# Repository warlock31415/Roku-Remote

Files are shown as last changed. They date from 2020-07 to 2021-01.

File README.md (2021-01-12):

# Roku Remote

## Introduction
My roomate keeps loosing the remote to the TV. So I made a spare remote to work with our TV and simulates the same behaviour as the original remote. The remote can also work via micro USB as well as a Lithium polymer battery. This project was my first forray into ARM microcontrollers and ST's Hardware Abstraction Layer (HAL).  

## Recording button codes
The Roku remote work on a IR signal and the data is modulated on the 37 kHz signal. The NEC protocol decription can be found [here](https://techdocs.altium.com/display/FPGA/NEC+Infrared+Transmission+Protocol) . A Analog Discovery along with the TSOP382 (IR receiver) was used to record the signal. The receiver demodulates the signal internally and only ouputs the data bits. Each button was pressed and the corresponding code was recorded. It was noted that each button had 2 codes associated with it. The first one was transmitted when the button was pressed and the second was transmitted when the button was held down. Only the last 4 bytes of the codes are shown here as the first 4 bytes are always the same (0x57E3).

The recorded button codes are as follows:
| Button | Code in HEX |  Last 4 bytes of the held down code|
|---|---| ---|
| Power  | 0x57E3E817 | 0x57E3E916 | 
| Back | 0x57E36699 | 0x57E36798 |
| Home | 0xCO3F | 0xC13E |
| ↑ | 0x9867 | 0x9966 |
| → | 0xB44B | 0xB54A |
| ↓ | 0xCC33 | 0xCD32 |
| ← | 0x7887 | 0x7986 |
| OK | 0x54AB | 0x55AA |
| V+ | 0xF00F | 0xF10E |
| V- | 0x08F7 | 0x09F6 |
| Mute | 0x04FB | 0x05FA |

## The code
ST's Nucleo-F401RE(497-14360-ND) was used to build the remote on a breadboard. Although, a STM32L052K8T was actually used in the final prototype due to its lower power consumption as compared to the STM32F401RE.

The HAL does not have a microsecond delay so a timer was used. The following code shows how this works:
```
void delay_us(uint16_t time)
{
	TIM6->ARR = time; 	 	// Load time into Auto Reload Register
	TIM6->CR1 |= (1<<0); 	// start timer

	while(TIM6->CR1 & 1);	// Wait for timer to elapse
}
```
ST's Cube IDE makes it very easy to set up and use timers graphically. To generate the carrier another 16-bit advanced timer was used in PWM mode. The STM32F401RE has 16-bit prescale register which allows just about any frequency. This, combined with the Auto-Preload Register, one can generate just about any frequency signal with any duty cycle. So a 37kHz carrier with a 30% duty cycle, for efficiency, was generated. This Prescale and AR registers are especially more advatageous to an ATMEGA328P which only has a couple of prescalers to choose from and the "auto reload register" is the only way to control frequency. And hence duty cycle cannot be controlled in the same way.

Each button code consists of 3 sections. The start code, specific button code and the end code. This can be seen in Table 1.
## PCB
The PCB was made in Eagle and manufactured by JLCPCB. All components were hand soldered. Including, the STM32L052K8T. The blue silk screen on the PCBs look pretty good. 
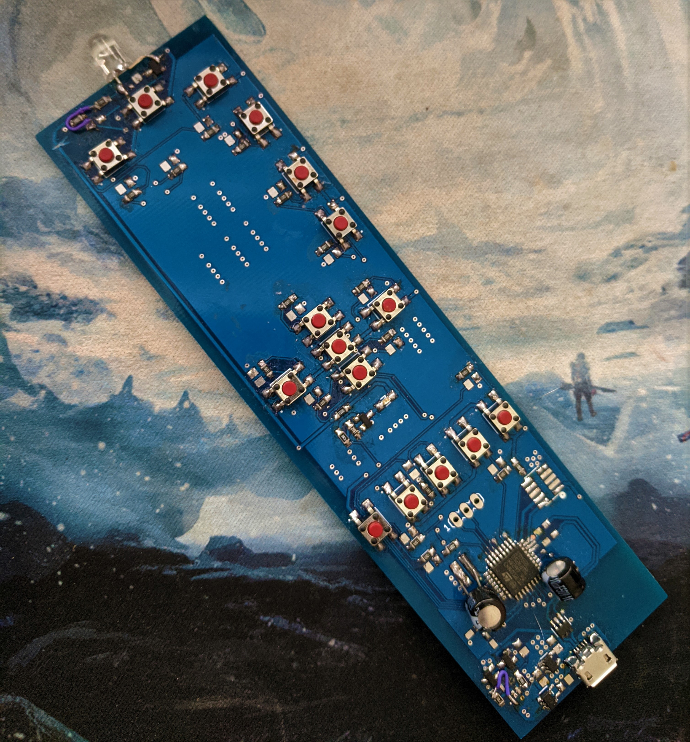
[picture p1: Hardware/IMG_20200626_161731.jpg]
PCB Image


## Shortcomings
- The SMD IR transmitter that was spec'd for the project didn't seem to work properly. So a THT transmitter, was was used to test the breadboard prototype, was soldered in its place. Some wire bodging was needed to accomplish this.
- The battery protection circuitry was not correctly wired up (Some kind of issue with Battery GND vs system GND).

## TO DO
- Redo board to eliminate wire bodges.
- Make a case for the board.

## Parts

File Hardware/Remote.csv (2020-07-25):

Qty | Value | Device | Package | Parts | Description | AVAILABILITY | BUILT_BY | COPYRIGHT | DESCRIPTION | DIGI-KEY_PART_NUMBER | DIGI-KEY_PURCHASE_URL | MANUFACTURER | MANUFACTURER_PART_NUMBER | MF | MP | MPN | OC_FARNELL | OC_NEWARK | PACKAGE | POPULARITY | PRICE | SOURCELIBRARY | SPICEPREFIX | VENDOR
1 |  | 20021121-00010C4LF | CONN_00010C4LF_AMP | J2 |  |  | EMA_Matt | Copyright (C) 2018 Accelerated Designs. All rights reserved |  |  |  |  | 20021121-00010C4LF |  |  |  |  |  |  |  |  | Amphenol_2019-10-30 |  | Amphenol
1 |  | MA03-1 | MA03-1 | SV1 | PIN HEADER |  |  |  |  |  |  |  |  |  |  |  | unknown | unknown
1 |  | MCP73811T-420I/OT | SOT95P280X145-5N | IC4 |  |  |  |  | Charger IC Lithium Ion/Polymer SOT-23-5 | MCP73811T-420I/OTCT-ND | https://www.digikey.com/product-detail/en/microchip-technology/MCP73811T-420I-OT/MCP73811T-420I-OTCT-ND/1649474 |  |  | Microchip | MCP73811T-420I/OT |  |  |  | SOT-23 Microchip
1 |  | S2B-PH-SM4-TB(LF)(SN) | JST_S2B-PH-SM4-TB(LF)(SN) | J1 | PH Series 2 Position 2 mm Pitch Surface Mount Side Entry Shrouded Header | Unavailable |  |  | Connector Header Surface Mount, Right Angle 2 position 0.079 _2.00mm_ |  |  |  |  | JST Sales | S2B-PH-SM4-TB_LF__SN_ |  |  |  | None |  | None
1 |  | TPS73632DBVTDBV5-M | DBV5-M | IC5 |  |  | EMA_UL_Team |  |  |  |  | Texas Instruments | TPS73632DBVT |  |  |  |  |  |  |  |  |  |  | Texas Instruments
1 | 100 | R-US_R0805W | R0805W | R22 | RESISTOR, American symbol |  |  |  |  |  |  |  |  |  |  |  |  |  |  | 0 |  |  | R
1 | 100k | R-US_R0805W | R0805W | R29 | RESISTOR, American symbol |  |  |  |  |  |  |  |  |  |  |  |  |  |  | 0 |  |  | R
20 | 100nF | C-USC0805K | C0805K | C1, C2, C4, C5, C6, C7, C8, C9, C10, C11, C12, C13, C14, C15, C16, C17, C18, C19, C20, C25 | CAPACITOR, American symbol |  |  |  |  |  |  |  |  |  |  |  |  |  |  | 19 |  |  | C
1 | 10118193-0001LF | 10118193-0001LF | FCI_10118193-0001LF | J3 | Micro USB B Type Receptacle |  |  |  | USB - micro B USB 2.0 Receptacle Connector 5 Position Surface Mount, Right Angle | Through Hole | 609-4616-1-ND | https://www.digikey.com/product-detail/en/amphenol-icc-fci/10118193-0001LF/609-4616-1-ND/2785380 |  |  | Amphenol ICC | 10118193-0001LF |  |  |  | None
4 | 10k | R-US_R0805W | R0805W | R1, R2, R23, R25 | RESISTOR, American symbol |  |  |  |  |  |  |  |  |  |  |  |  |  |  | 0 |  |  | R
2 | 10uF | C-USC0805K | C0805K | C3, C21 | CAPACITOR, American symbol |  |  |  |  |  |  |  |  |  |  |  |  |  |  | 19 |  |  | C
16 | 1k | R-US_R0805W | R0805W | R3, R4, R5, R6, R7, R8, R9, R10, R11, R12, R13, R14, R15, R16, R17, R18 | RESISTOR, American symbol |  |  |  |  |  |  |  |  |  |  |  |  |  |  | 0 |  |  | R
3 | 1uF | C-USC0805K | C0805K | C22, C23, C24 | CAPACITOR, American symbol |  |  |  |  |  |  |  |  |  |  |  |  |  |  | 19 |  |  | C
1 | 2.7k | R-US_R0805W | R0805W | R27 | RESISTOR, American symbol |  |  |  |  |  |  |  |  |  |  |  |  |  |  | 0 |  |  | R
3 | 22 | R-US_R0805W | R0805W | R19, R20, R30 | RESISTOR, American symbol |  |  |  |  |  |  |  |  |  |  |  |  |  |  | 0 |  |  | R
1 | 330 | R-US_R0805W | R0805W | R28 | RESISTOR, American symbol |  |  |  |  |  |  |  |  |  |  |  |  |  |  | 0 |  |  | R
2 | 470 | R-US_R0805W | R0805W | R24, R26 | RESISTOR, American symbol |  |  |  |  |  |  |  |  |  |  |  |  |  |  | 0 |  |  | R
1 | 50k | R-US_R0805W | R0805W | R21 | RESISTOR, American symbol |  |  |  |  |  |  |  |  |  |  |  |  |  |  | 0 |  |  | R
1 | AP9101CK6-CQTRG1 | AP9101CK6-CQTRG1 | SOT95P280X140-6N | IC6 | None | Unavailable |  |  | Battery Battery Protection IC Lithium Ion/Polymer SOT-26 |  |  |  |  | Diodes Inc. | AP9101CK6-CQTRG1 |  |  |  | SOT-23 Diodes Inc. |  | None
1 | APA3010SF4C | APA3010SF4C | APA3010SF4C | D1 | DIO-10854 |  |  |  | Infrared _IR_ Emitter 880nm 1.3V 50mA 0.4mW/sr @ 20mA 120° 2-SMD, No Lead | 754-1070-1-ND | https://www.digikey.com/product-detail/en/kingbright/APA3010SF4C/754-1070-1-ND/1747787 |  |  | Kingbright | APA3010SF4C |  |  |  | SMD-2 Kingbright
4 | BSS138 | BSS138 | BSS138 | IC2, IC3, IC7, IC8 | BSS138 | Unavailable |  |  | N-Channel 50V 220mA _Ta_ 360mW _Ta_ Surface Mount SOT-23-3 |  |  |  |  | MICROSS/On Semiconductor | BSS138 |  |  |  | TO-236-3 Micross |  | None
1 | STM32L052K8T | STM32L052K8T | QFP80P900X900X160-32N | IC1
16 | TL3305AF260QG | TL3305AF260QG | SW_TL3305AF260QG | SW1, SW2, SW3, SW4, SW5, SW6, SW7, SW8, SW9, SW10, SW11, SW12, SW13, SW14, SW15, SW16 | Switch Tactile Spst-No 50ma 12v |  |  |  | Tactile Switch SPST-NO Top Actuated Surface Mount | EG5353CT-ND | https://www.digikey.com/product-detail/en/e-switch/TL3305AF260QG/EG5353CT-ND/5816198 |  |  | E-Switch | TL3305AF260QG |  |  |  | LQFP-48 E-Switch
1 | USBLC6-2SC6SOT23-6L-M | USBLC6-2SC6SOT23-6L-M | SOT23-6L-M | IC9 |  |  | EMA_UL_Team |  |  |  |  |  | USBLC6-2SC6 |  |  |  |  |  |  |  |  |  |  | STMicroelectronics
1 | WL-SMCW-150120GS75000-G | WL-SMCW-150120GS75000-G | WL-SMCW_1206 | D2 | SMD mono-color Chip LED | Unavailable |  |  | Green 570nm LED Indication - Discrete 2V 0603 _1608 Metric_ |  |  |  |  | Wurth Electronics | 150060VS75000 |  |  |  | 0603 Wurth Electronics |  | None

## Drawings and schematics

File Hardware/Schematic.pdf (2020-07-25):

A

A

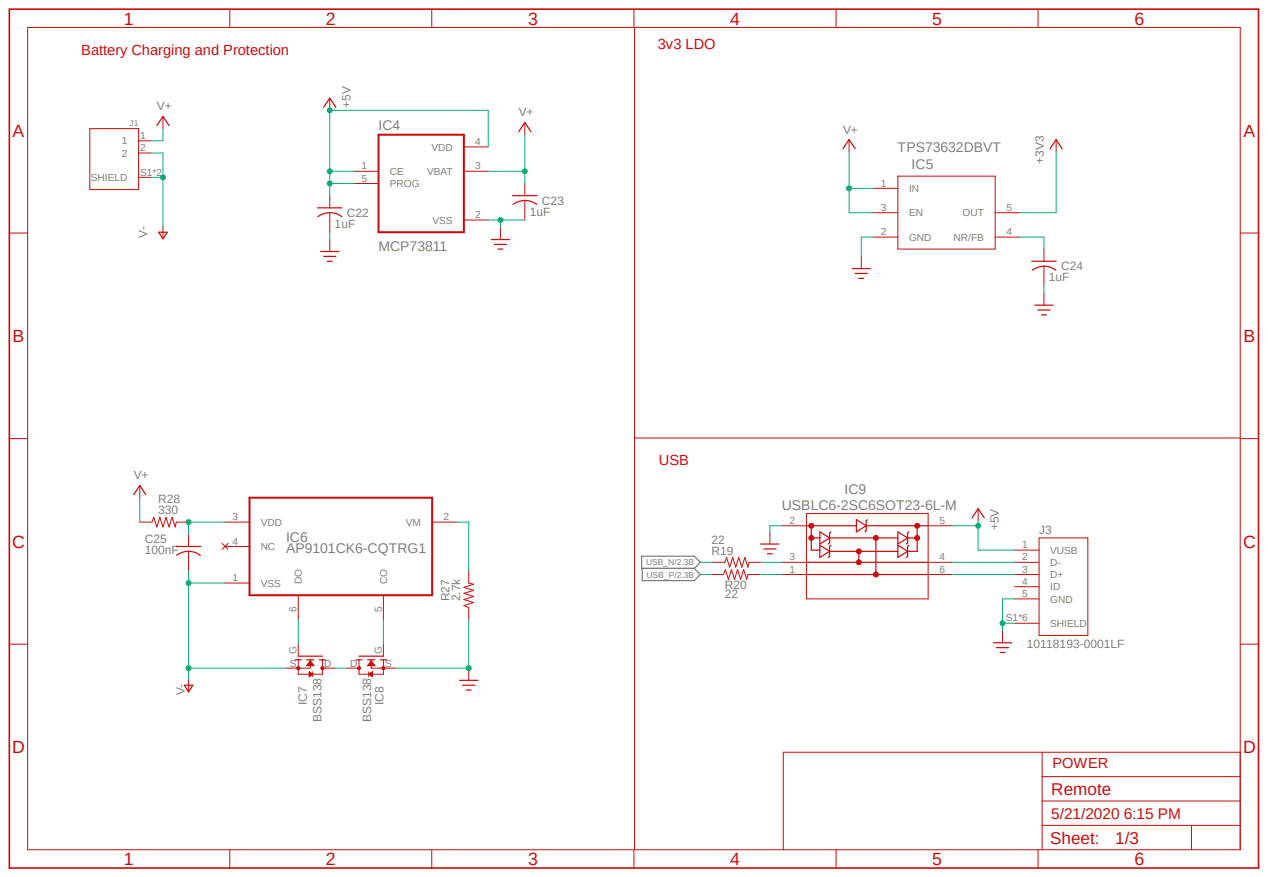
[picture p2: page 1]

C | IC9 USBLC6-2SC6SOT23-6L-M | C

# 10k ⁺³V³

A

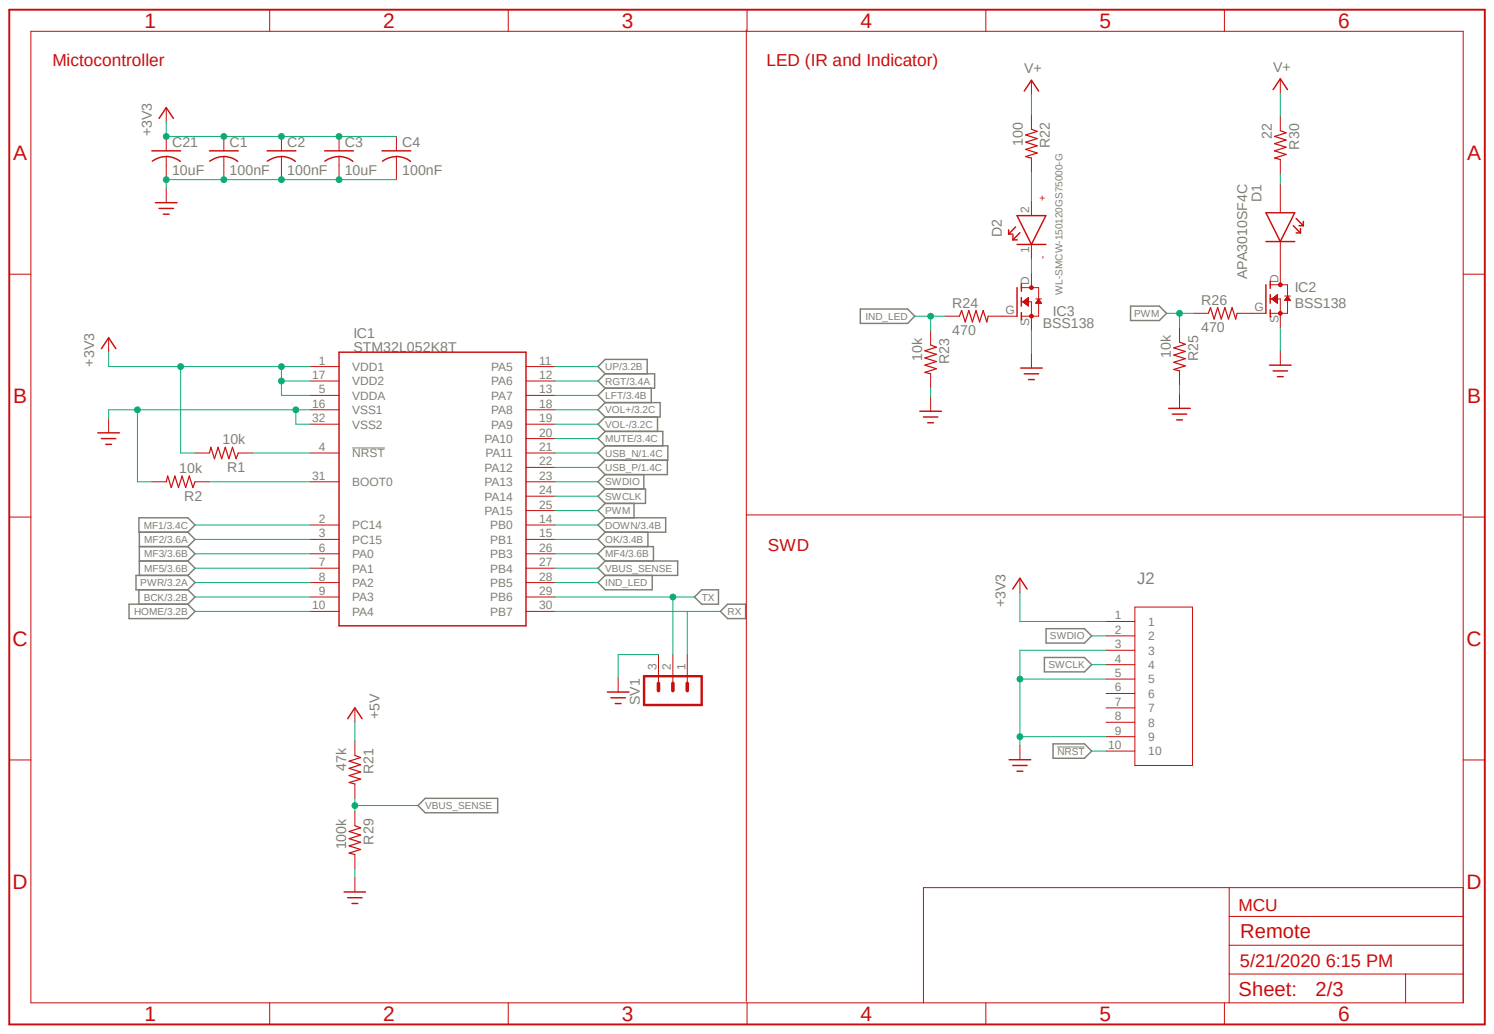
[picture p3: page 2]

# 100nF +3V³

A

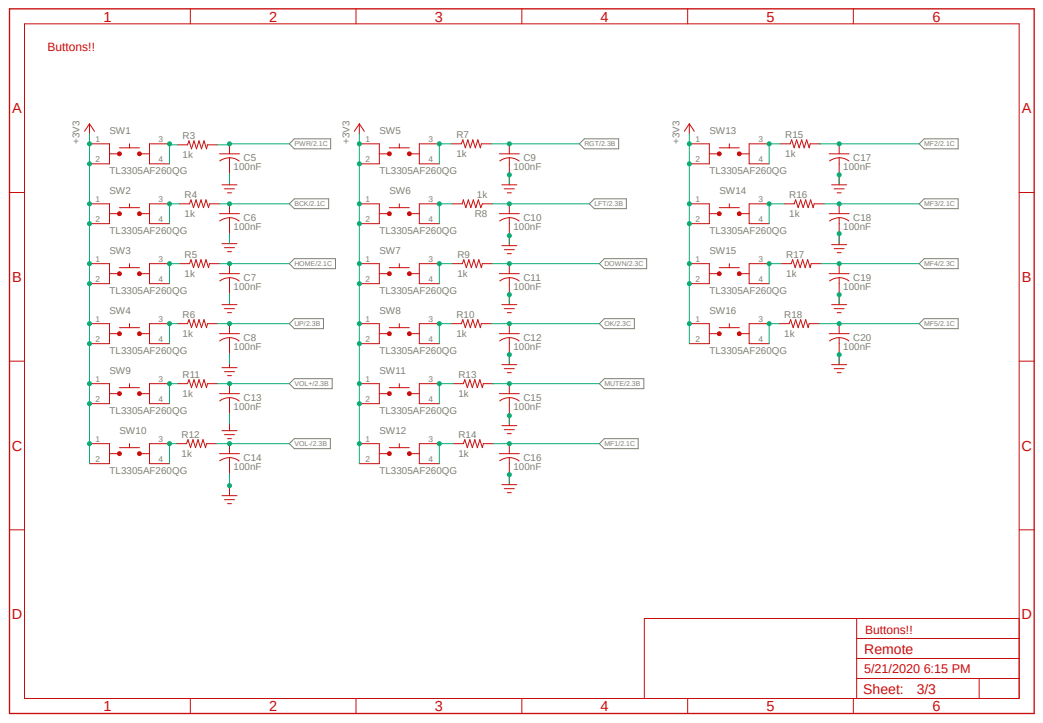
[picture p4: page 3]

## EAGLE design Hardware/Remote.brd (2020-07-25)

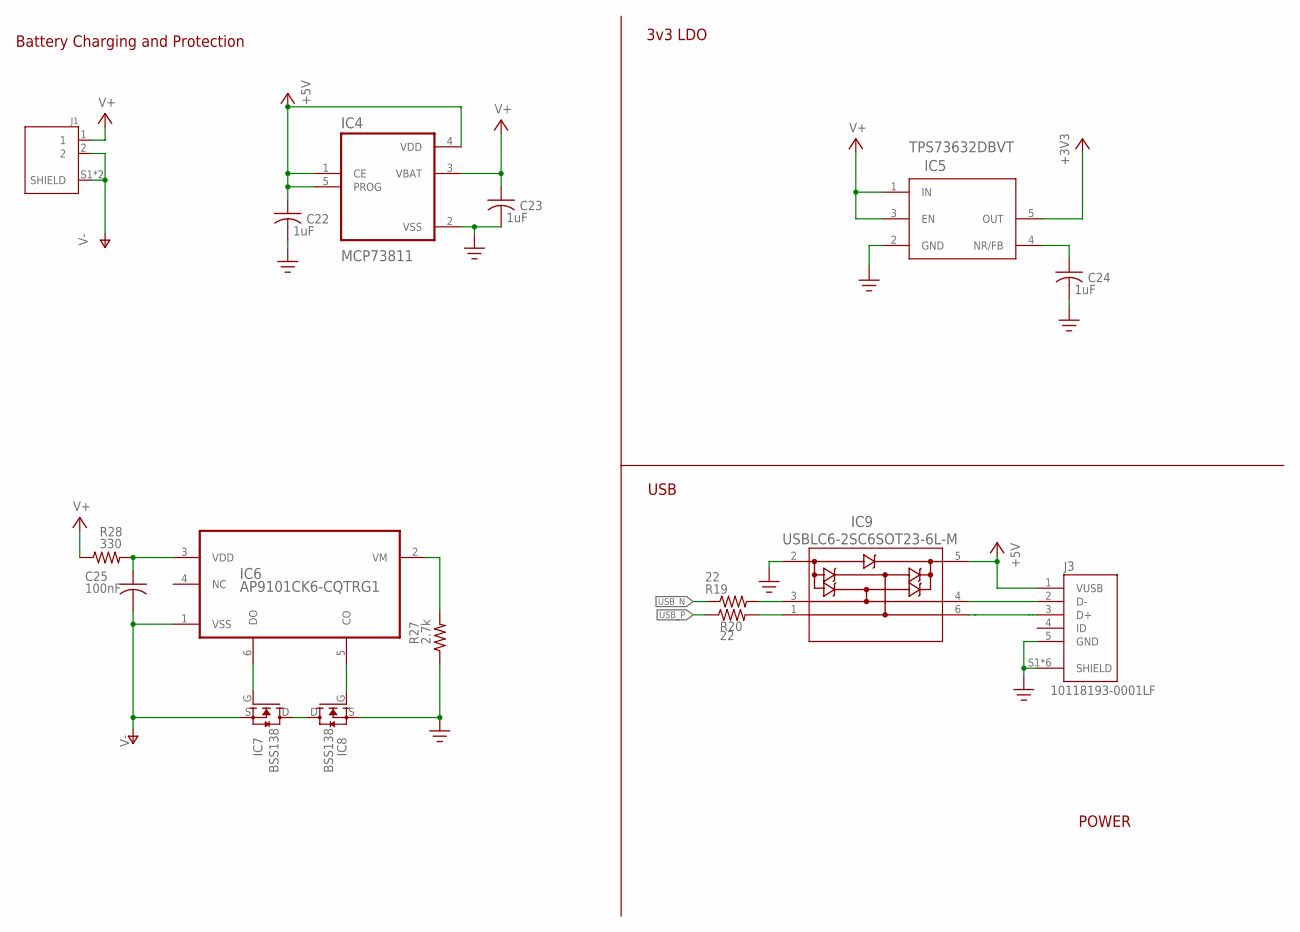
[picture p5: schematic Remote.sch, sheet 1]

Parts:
C22, C23, C24: 1uF; C0805K
C25: 100nF; C0805K
IC4: MCP73811; SOT95P280X145-5N
IC5: TPS73632DBVT; DBV5-M
IC6: AP9101CK6-CQTRG1; SOT95P280X140-6N
IC7, IC8: BSS138
IC9: USBLC6-2SC6SOT23-6L-M; SOT23-6L-M
J1: S2B-PH-SM4-TB(LF)(SN); JST_S2B-PH-SM4-TB(LF)(SN)
J3: 10118193-0001LF; FCI_10118193-0001LF
R19, R20: 22; R0805W
R27: 2.7k; R0805W
R28: 330; R0805W

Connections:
+3V3: IC5.5 (OUT); also elsewhere on the board
+5V: C22.1, IC4.1 (CE), IC4.4 (VDD), IC4.5 (PROG), IC9.5 (VBUS), J3.1 (VUSB); also elsewhere on the board
GND: C22.2, C23.2, C24.2, IC4.2 (VSS), IC5.2 (GND), IC8.S, IC9.2 (GND), J3.5 (GND), J3.S1 (SHIELD), J3.S2 (SHIELD), J3.S3 (SHIELD), J3.S4 (SHIELD), J3.S5 (SHIELD), J3.S6 (SHIELD), R27.1; also elsewhere on the board
unnamed: IC6.6 (DO), IC7.G
unnamed: IC6.5 (CO), IC8.G
unnamed: IC7.D, IC8.D
unnamed: C24.1, IC5.4 (NR/FB)
unnamed: IC6.2 (VM), R27.2
unnamed: C25.1, IC6.3 (VDD), R28.2
USB2_N: IC9.4 (I/O2), J3.2 (D-)
USB2_P: IC9.6 (I/O1), J3.3 (D+)
USB3_N: IC9.3 (I/O2_2), R19.2
USB3_P: IC9.1 (I/O1_2), R20.2
USB_N: R19.1; also elsewhere on the board
USB_P: R20.1; also elsewhere on the board
V+: C23.1, IC4.3 (VBAT), IC5.1 (IN), IC5.3 (EN), J1.1, R28.1; also elsewhere on the board
V-: C25.2, IC6.1 (VSS), IC7.S, J1.2, J1.S1 (SHIELD), J1.S2 (SHIELD)

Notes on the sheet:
Battery Charging and Protection
3v3 LDO
USB
POWER

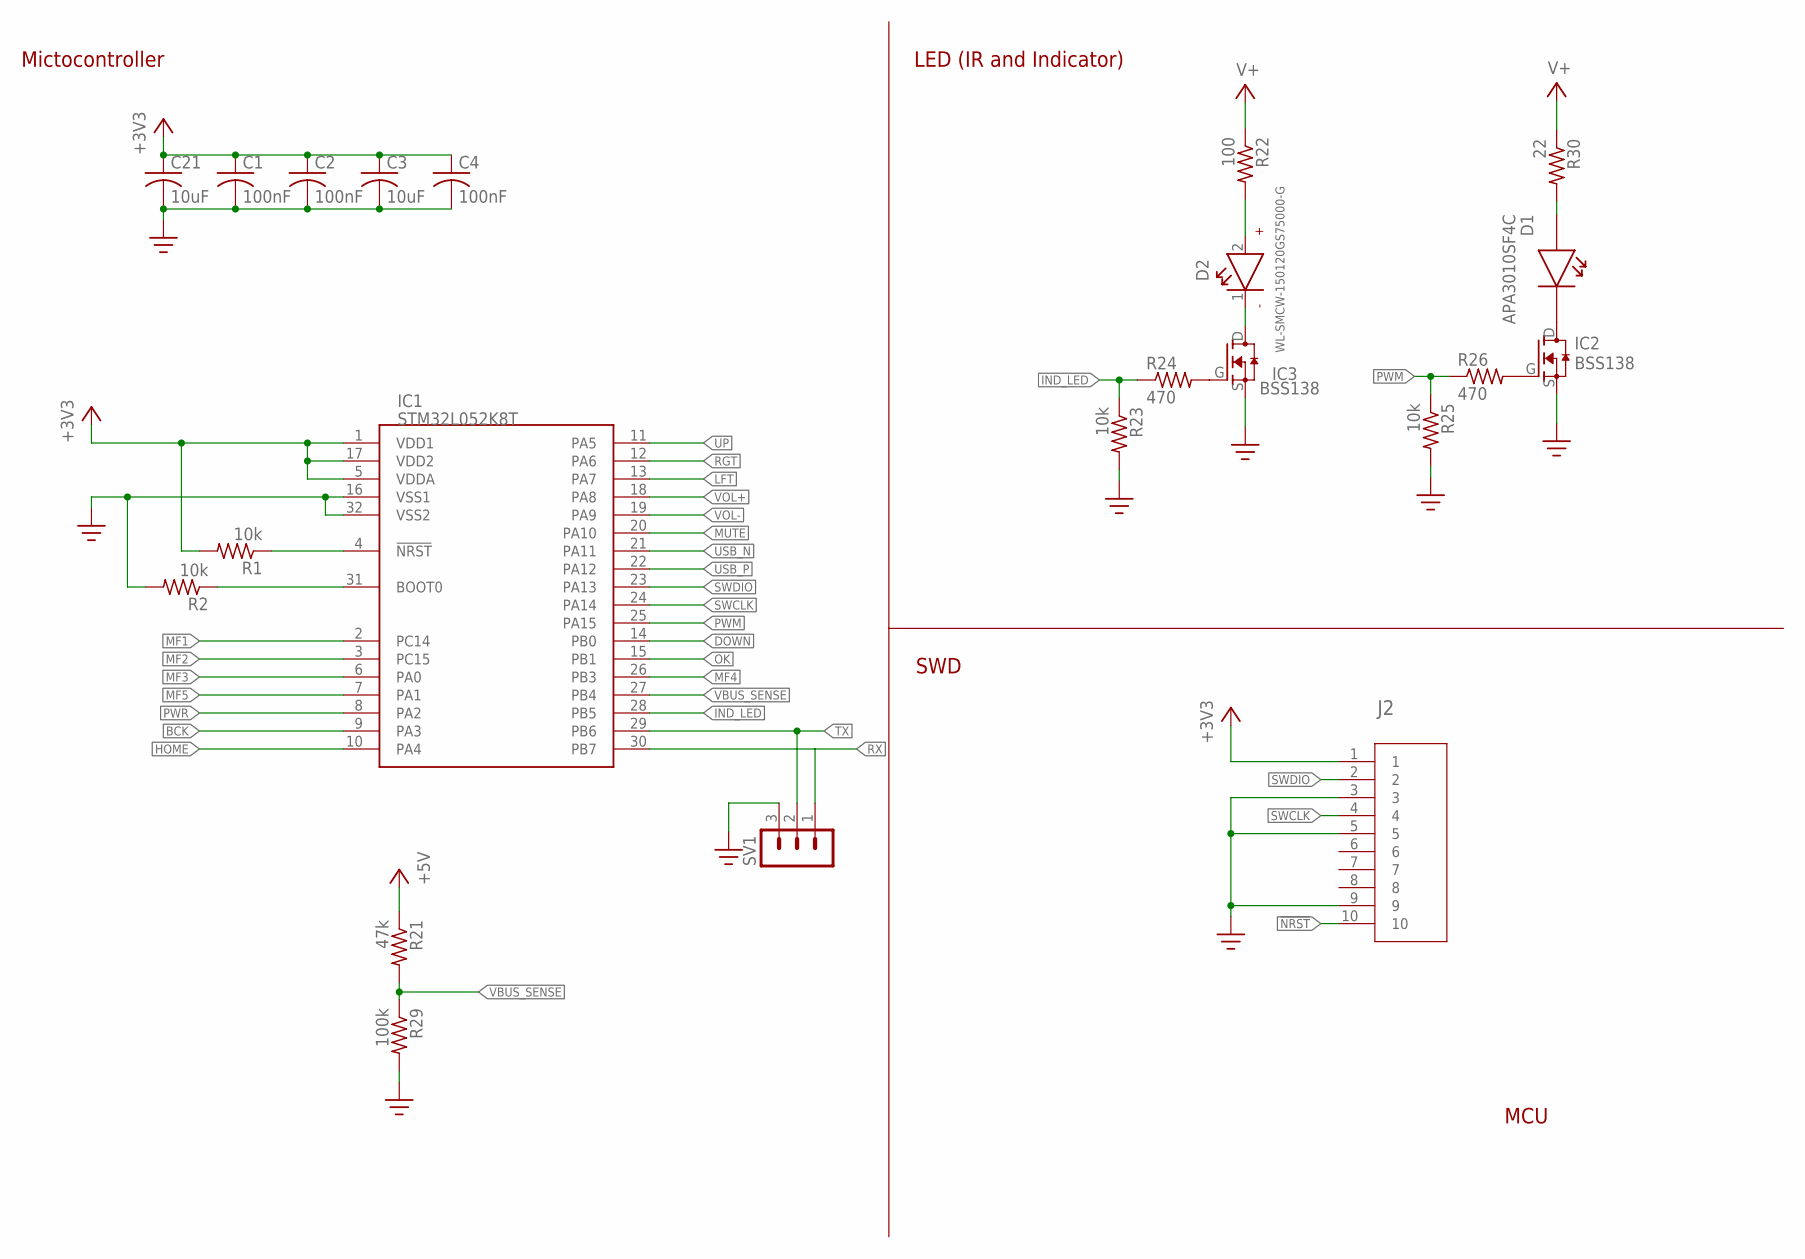
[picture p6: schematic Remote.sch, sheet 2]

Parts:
C1, C2, C4: 100nF; C0805K
C3, C21: 10uF; C0805K
D1: APA3010SF4C
D2: WL-SMCW-150120GS75000-G; WL-SMCW_1206
IC1: STM32L052K8T; QFP80P900X900X160-32N
IC2, IC3: BSS138
J2: 20021121-00010C4LF; CONN_00010C4LF_AMP
R1, R2, R23, R25: 10k; R0805W
R21: 47k; R0805W
R22: 100; R0805W
R24, R26: 470; R0805W
R29: 100k; R0805W
R30: 22; R0805W
SV1: MA03-1

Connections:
!NRST: IC1.4 (!NRST), J2.10, R1.1
+3V3: C1.1, C2.1, C3.1, C4.1, C21.1, IC1.1 (VDD1), IC1.5 (VDDA), IC1.17 (VDD2), J2.1, R1.2; also elsewhere on the board
+5V: R21.1; also elsewhere on the board
BCK: IC1.9 (PA3); also elsewhere on the board
DOWN: IC1.14 (PB0); also elsewhere on the board
GND: C1.2, C2.2, C3.2, C4.2, C21.2, IC1.16 (VSS1), IC1.32 (VSS2), IC2.S, IC3.S, J2.3, J2.5, J2.9, R2.2, R23.2, R25.2, R29.2, SV1.3; also elsewhere on the board
HOME: IC1.10 (PA4); also elsewhere on the board
IND_LED: IC1.28 (PB5), R23.1, R24.1
LFT: IC1.13 (PA7); also elsewhere on the board
MF1: IC1.2 (PC14); also elsewhere on the board
MF2: IC1.3 (PC15); also elsewhere on the board
MF3: IC1.6 (PA0); also elsewhere on the board
MF4: IC1.26 (PB3); also elsewhere on the board
MF5: IC1.7 (PA1); also elsewhere on the board
MUTE: IC1.20 (PA10); also elsewhere on the board
unnamed: D1.1, R30.2
unnamed: IC1.31 (BOOT0), R2.1
unnamed: D1.2, IC2.D
unnamed: D2.2 (+), R22.2
unnamed: D2.1 (-), IC3.D
unnamed: IC2.G, R26.2
unnamed: IC3.G, R24.2
OK: IC1.15 (PB1); also elsewhere on the board
PWM: IC1.25 (PA15), R25.1, R26.1
PWR: IC1.8 (PA2); also elsewhere on the board
RGT: IC1.12 (PA6); also elsewhere on the board
RX: IC1.30 (PB7), SV1.1
SWCLK: IC1.24 (PA14), J2.4
SWDIO: IC1.23 (PA13), J2.2
TX: IC1.29 (PB6), SV1.2
UP: IC1.11 (PA5); also elsewhere on the board
USB_N: IC1.21 (PA11); also elsewhere on the board
USB_P: IC1.22 (PA12); also elsewhere on the board
V+: R22.1, R30.1; also elsewhere on the board
VBUS_SENSE: IC1.27 (PB4), R21.2, R29.1
VOL+: IC1.18 (PA8); also elsewhere on the board
VOL-: IC1.19 (PA9); also elsewhere on the board

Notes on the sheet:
Mictocontroller
LED (IR and Indicator)
SWD
MCU

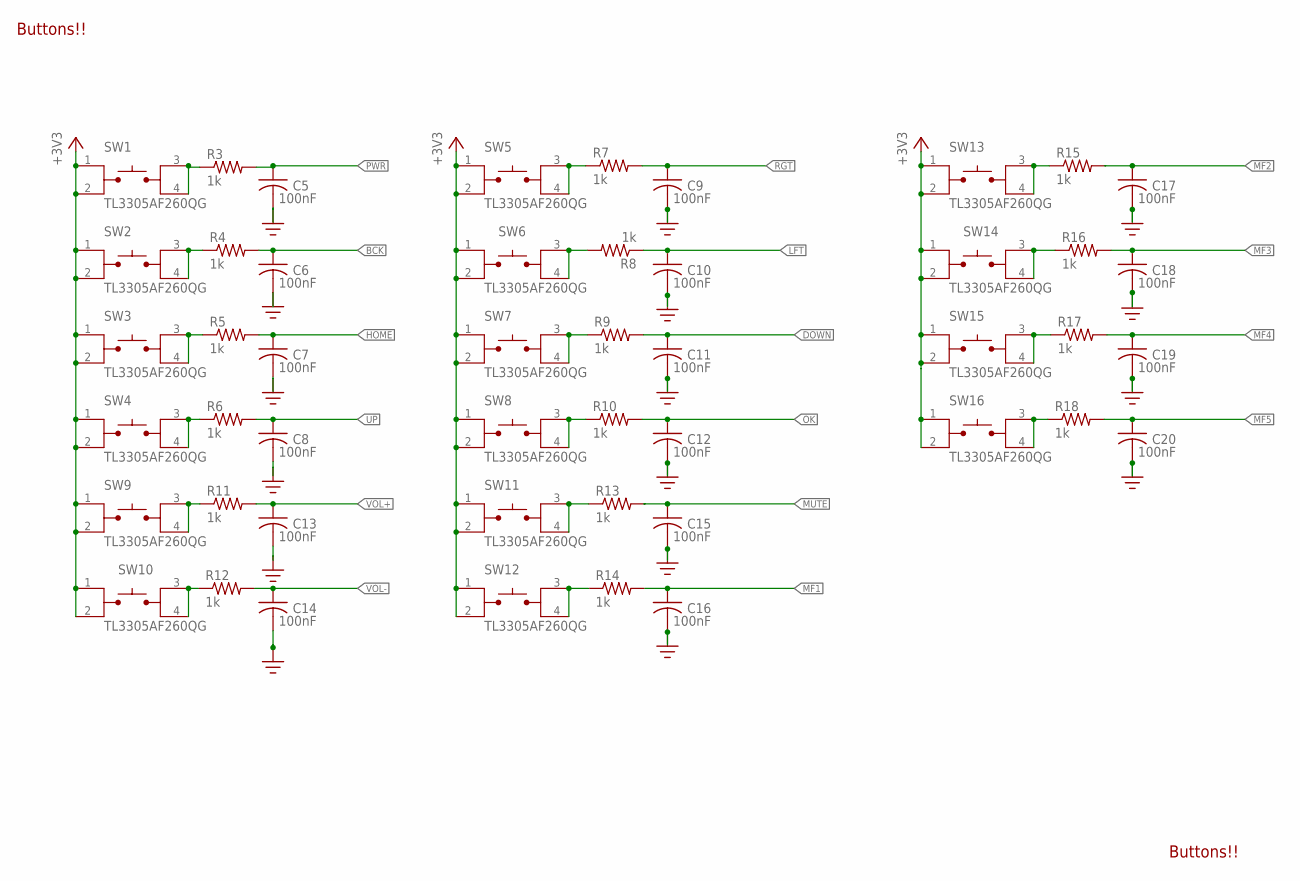
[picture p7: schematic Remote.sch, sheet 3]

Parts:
C5, C6, C7, C8, C9, C10, C11, C12, C13, C14, C15, C16, C17, C18, C19, C20: 100nF; C0805K
R3, R4, R5, R6, R7, R8, R9, R10, R11, R12, R13, R14, R15, R16, R17, R18: 1k; R0805W
SW1, SW2, SW3, SW4, SW5, SW6, SW7, SW8, SW9, SW10, SW11, SW12, SW13, SW14, SW15, SW16: TL3305AF260QG; SW_TL3305AF260QG

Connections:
+3V3: SW1.1, SW1.2, SW2.1, SW2.2, SW3.1, SW3.2, SW4.1, SW4.2, SW5.1, SW5.2, SW6.1, SW6.2, SW7.1, SW7.2, SW8.1, SW8.2, SW9.1, SW9.2, SW10.1, SW10.2, SW11.1, SW11.2, SW12.1, SW12.2, SW13.1, SW13.2, SW14.1, SW14.2, SW15.1, SW15.2, SW16.1, SW16.2; also elsewhere on the board
BCK: C6.1, R4.2; also elsewhere on the board
DOWN: C11.1, R9.2; also elsewhere on the board
GND: C5.2, C6.2, C7.2, C8.2, C9.2, C10.2, C11.2, C12.2, C13.2, C14.2, C15.2, C16.2, C17.2, C18.2, C19.2, C20.2; also elsewhere on the board
HOME: C7.1, R5.2; also elsewhere on the board
LFT: C10.1, R8.1; also elsewhere on the board
MF1: C16.1, R14.2; also elsewhere on the board
MF2: C17.1, R15.2; also elsewhere on the board
MF3: C18.1, R16.2; also elsewhere on the board
MF4: C19.1, R17.2; also elsewhere on the board
MF5: C20.1, R18.2; also elsewhere on the board
MUTE: C15.1, R13.2; also elsewhere on the board
unnamed: R3.1, SW1.3, SW1.4
unnamed: R4.1, SW2.3, SW2.4
unnamed: R5.1, SW3.3, SW3.4
unnamed: R6.1, SW4.3, SW4.4
unnamed: R11.1, SW9.3, SW9.4
unnamed: R12.1, SW10.3, SW10.4
unnamed: R7.1, SW5.3, SW5.4
unnamed: R8.2, SW6.3, SW6.4
unnamed: R9.1, SW7.3, SW7.4
unnamed: R10.1, SW8.3, SW8.4
unnamed: R13.1, SW11.3, SW11.4
unnamed: R14.1, SW12.3, SW12.4
unnamed: R15.1, SW13.3, SW13.4
unnamed: R16.1, SW14.3, SW14.4
unnamed: R17.1, SW15.3, SW15.4
unnamed: R18.1, SW16.3, SW16.4
OK: C12.1, R10.2; also elsewhere on the board
PWR: C5.1, R3.2; also elsewhere on the board
RGT: C9.1, R7.2; also elsewhere on the board
UP: C8.1, R6.2; also elsewhere on the board
VOL+: C13.1, R11.2; also elsewhere on the board
VOL-: C14.1, R12.2; also elsewhere on the board

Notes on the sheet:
Buttons!!

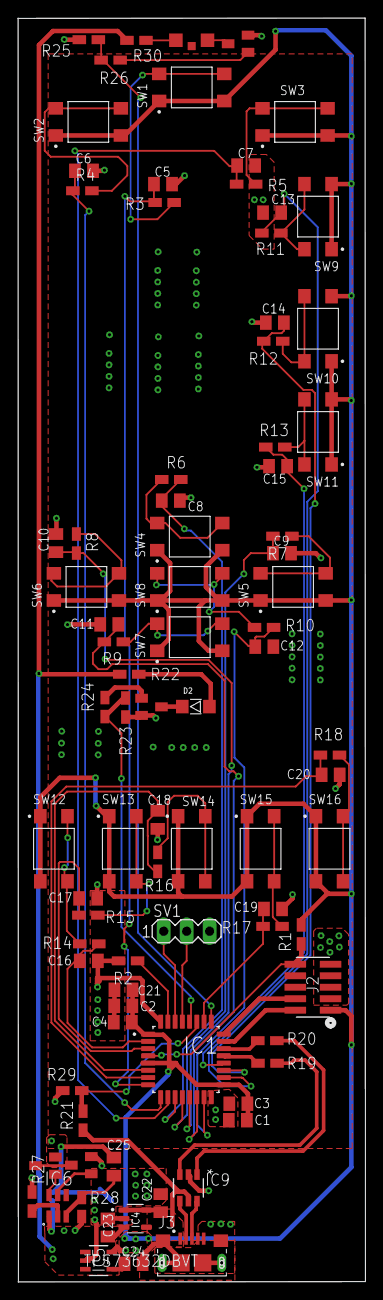
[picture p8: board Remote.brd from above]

Board: 2 copper layers, 38.4 x 139.8 mm, 86 parts (1 on the bottom side), 64 nets.

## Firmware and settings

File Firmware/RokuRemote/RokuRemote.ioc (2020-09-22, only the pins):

Mcu.UserName=STM32L052K8Tx
PA0.GPIO_Label=MF3
PA0.Signal=GPIO_Input
PA1.GPIO_Label=MF5
PA1.Signal=GPIO_Input
PA10.GPIO_Label=MUTE
PA10.Signal=GPXTI10
PA11.Signal=USB_DM
PA12.Signal=USB_DP
PA13.Signal=SYS_SWDIO
PA14.Signal=SYS_SWCLK
PA15.GPIO_Label=PWM
PA15.Signal=S_TIM2_CH1
PA2.GPIO_Label=PWR
PA2.Signal=GPXTI2
PA3.GPIO_Label=BCK
PA3.Signal=GPXTI3
PA4.GPIO_Label=HOME
PA4.Signal=GPXTI4
PA5.GPIO_Label=UP
PA5.Signal=GPXTI5
PA6.GPIO_Label=RGT
PA6.Signal=GPXTI6
PA7.GPIO_Label=LFT
PA7.Signal=GPXTI7
PA8.GPIO_Label=V+
PA8.Signal=GPXTI8
PA9.GPIO_Label=V-
PA9.Signal=GPXTI9
PB0.GPIO_Label=DWN
PB0.Signal=GPXTI0
PB1.GPIO_Label=OK
PB1.Signal=GPXTI1
PB3.GPIO_Label=MF4
PB3.Signal=GPIO_Input
PB4.GPIO_Label=USB_SENSE
PB4.Signal=GPIO_Input
PB5.GPIO_Label=LED_IND
PB5.Signal=GPIO_Output
PB6.Signal=USART1_TX
PB7.Signal=USART1_RX
PC14-OSC32_IN.GPIO_Label=MF1
PC14-OSC32_IN.Signal=GPIO_Input
PC15-OSC32_OUT.GPIO_Label=MF2
PC15-OSC32_OUT.Signal=GPIO_Input

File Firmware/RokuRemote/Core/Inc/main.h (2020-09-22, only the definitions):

#define MF1_Pin GPIO_PIN_14
#define MF1_GPIO_Port GPIOC
#define MF2_Pin GPIO_PIN_15
#define MF2_GPIO_Port GPIOC
#define MF3_Pin GPIO_PIN_0
#define MF3_GPIO_Port GPIOA
#define MF5_Pin GPIO_PIN_1
#define MF5_GPIO_Port GPIOA
#define PWR_Pin GPIO_PIN_2
#define PWR_GPIO_Port GPIOA
#define PWR_EXTI_IRQn EXTI2_3_IRQn
#define BCK_Pin GPIO_PIN_3
#define BCK_GPIO_Port GPIOA
#define BCK_EXTI_IRQn EXTI2_3_IRQn
#define HOME_Pin GPIO_PIN_4
#define HOME_GPIO_Port GPIOA
#define HOME_EXTI_IRQn EXTI4_15_IRQn
#define UP_Pin GPIO_PIN_5
#define UP_GPIO_Port GPIOA
#define UP_EXTI_IRQn EXTI4_15_IRQn
#define RGT_Pin GPIO_PIN_6
#define RGT_GPIO_Port GPIOA
#define RGT_EXTI_IRQn EXTI4_15_IRQn
#define LFT_Pin GPIO_PIN_7
#define LFT_GPIO_Port GPIOA
#define LFT_EXTI_IRQn EXTI4_15_IRQn
#define DWN_Pin GPIO_PIN_0
#define DWN_GPIO_Port GPIOB
#define DWN_EXTI_IRQn EXTI0_1_IRQn
#define OK_Pin GPIO_PIN_1
#define OK_GPIO_Port GPIOB
#define OK_EXTI_IRQn EXTI0_1_IRQn
#define V__Pin GPIO_PIN_8
#define V__GPIO_Port GPIOA
#define V__EXTI_IRQn EXTI4_15_IRQn
#define V_A9_Pin GPIO_PIN_9
#define V_A9_GPIO_Port GPIOA
#define V_A9_EXTI_IRQn EXTI4_15_IRQn
#define MUTE_Pin GPIO_PIN_10
#define MUTE_GPIO_Port GPIOA
#define MUTE_EXTI_IRQn EXTI4_15_IRQn
#define PWM_Pin GPIO_PIN_15
#define PWM_GPIO_Port GPIOA
#define MF4_Pin GPIO_PIN_3
#define MF4_GPIO_Port GPIOB
#define USB_SENSE_Pin GPIO_PIN_4
#define USB_SENSE_GPIO_Port GPIOB
#define LED_IND_Pin GPIO_PIN_5
#define LED_IND_GPIO_Port GPIOB

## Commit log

2020-09-22 Made separate folders for Hardware and firmware moved appropriate files
    [Remote.brd, Remote.csv, Remote.sch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]
2020-09-22 Added a image of the PCB

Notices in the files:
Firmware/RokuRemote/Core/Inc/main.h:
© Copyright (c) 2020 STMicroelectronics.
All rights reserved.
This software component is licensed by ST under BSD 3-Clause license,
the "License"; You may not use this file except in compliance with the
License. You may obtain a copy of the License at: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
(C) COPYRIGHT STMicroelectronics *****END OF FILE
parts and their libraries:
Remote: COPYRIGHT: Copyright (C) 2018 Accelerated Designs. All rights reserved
